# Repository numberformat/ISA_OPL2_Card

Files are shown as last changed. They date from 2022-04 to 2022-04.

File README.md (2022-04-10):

# README

ISA OPL2 Card is a sound card based on Yamaha OPL2 chip, officially known as YM3812. This card is compatible with the AdLib Music Synthesizer Card that was very popular in late 80's - early
90's.

This card is based on a [design from Sergey Kiselev](http://www.malinov.com/Home/sergeys-projects/isa-opl2-card) with the modifications listed in the Revisions Section below.

## Revisions

NOAMi r1
- Added additional footprint for a more commonly available RK097N potentiometer
- Made connector pads shorter since half of them were not making contact with the connector pins.

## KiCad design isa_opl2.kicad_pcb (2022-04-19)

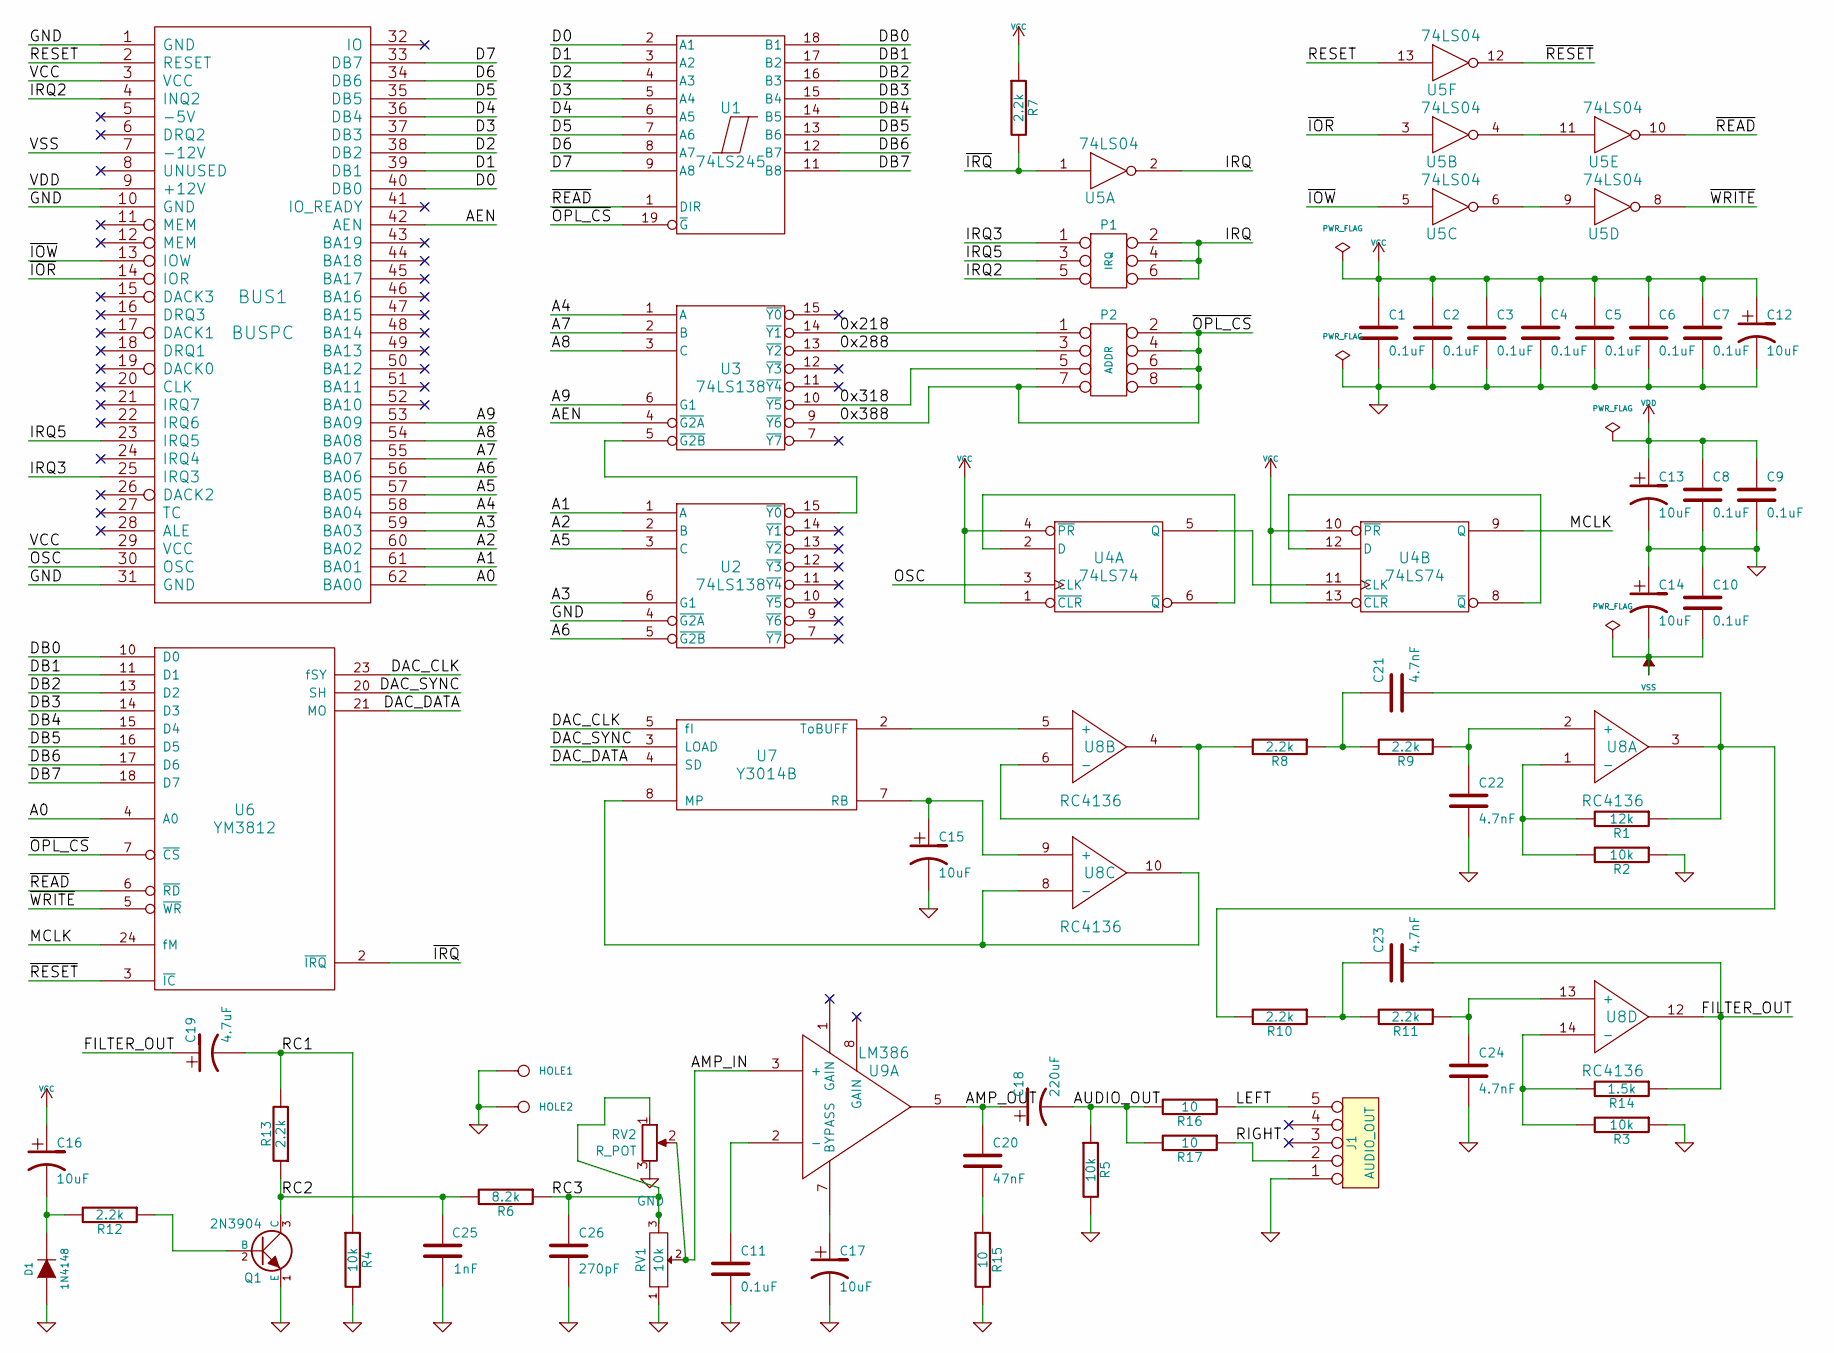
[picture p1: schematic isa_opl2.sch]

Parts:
BUS1: BUSPC
C1, C2, C3, C4, C5, C6, C7, C8, C9, C10, C11: 0.1uF
C12, C13, C14, C15, C16, C17: 10uF
C18: 220uF
C19: 4.7uF
C20: 47nF
C21, C22, C23, C24: 4.7nF
C25: 1nF
C26: 270pF
D1: 1N4148
HOLE1, HOLE2: CONN_1
J1: AUDIO_OUT
P1: IRQ
P2: ADDR
Q1: 2N3904
R1: 12k
R2, R3, R4, R5: 10k
R6: 8.2k
R7, R8, R9, R10, R11, R12, R13: 2.2k
R14: 1.5k
R15, R16, R17: 10
RV1: 10k
RV2: R_POT; Potentiometer_Vishay_T73XW_Horizontal
U1: 74LS245
U2, U3: 74LS138
U4: 74LS74
U5: 74LS04
U6: YM3812
U7: Y3014B
U8: RC4136
U9: LM386

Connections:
/0x218: P2.1, U3.14 (~Y1)
/0x288: P2.3, U3.13 (~Y2)
/0x318: P2.5, U3.10 (~Y5)
/0x388: P2.2, P2.4, P2.6, P2.7, P2.8, U1.19 (~G), U3.9 (~Y6), U6.7 (~CS)
/A0: BUS1.62 (BA00), U6.4 (A0)
/A1: BUS1.61 (BA01), U2.1 (A)
/A2: BUS1.60 (BA02), U2.2 (B)
/A3: BUS1.59 (BA03), U2.6 (G1)
/A4: BUS1.58 (BA04), U3.1 (A)
/A5: BUS1.57 (BA05), U2.3 (C)
/A6: BUS1.56 (BA06), U2.5 (~G2B)
/A7: BUS1.55 (BA07), U3.2 (B)
/A8: BUS1.54 (BA08), U3.3 (C)
/A9: BUS1.53 (BA09), U3.6 (G1)
/AEN: BUS1.42 (AEN), U3.4 (~G2A)
/AMP_IN: RV1.2, RV2.2, U9.3 (+)
/AMP_OUT: C18.1, C20.1, U9.5
/AUDIO_OUT: C18.2, R5.1, R16.2, R17.2
/D0: BUS1.40 (DB0), U1.2 (A1)
/D1: BUS1.39 (DB1), U1.3 (A2)
/D2: BUS1.38 (DB2), U1.4 (A3)
/D3: BUS1.37 (DB3), U1.5 (A4)
/D4: BUS1.36 (DB4), U1.6 (A5)
/D5: BUS1.35 (DB5), U1.7 (A6)
/D6: BUS1.34 (DB6), U1.8 (A7)
/D7: BUS1.33 (DB7), U1.9 (A8)
/DAC_CLK: U6.23 (fSY), U7.5 (fI)
/DAC_DATA: U6.21 (MO), U7.4 (SD)
/DAC_SYNC: U6.20 (SH), U7.3 (LOAD)
/DB0: U1.18 (B1), U6.10 (D0)
/DB1: U1.17 (B2), U6.11 (D1)
/DB2: U1.16 (B3), U6.13 (D2)
/DB3: U1.15 (B4), U6.14 (D3)
/DB4: U1.14 (B5), U6.15 (D4)
/DB5: U1.13 (B6), U6.16 (D5)
/DB6: U1.12 (B7), U6.17 (D6)
/DB7: U1.11 (B8), U6.18 (D7)
/FILTER_OUT: C19.1, C23.2, R14.1, U8.12
/IRQ: P1.2, P1.4, P1.6, U5.2
/IRQ2: BUS1.4 (INQ2), P1.5
/IRQ3: BUS1.25 (IRQ3), P1.1
/IRQ5: BUS1.23 (IRQ5), P1.3
/LEFT: J1.5, R16.1
/MCLK: U4.9 (Q), U6.24 (fM)
/OSC: BUS1.30 (OSC), U4.3 (CLK)
/RC1: C19.2, R4.1, R13.2
/RC2: C25.2, Q1.3 (C), R6.2, R13.1
/RC3: C26.1, R6.1, RV1.3, RV2.1
/RESET: BUS1.2 (RESET), U5.13
/RIGHT: J1.2, R17.1
/~IOR: BUS1.14 (IOR), U5.3
/~IOW: BUS1.13 (IOW), U5.5
/~IRQ: R7.2, U5.1, U6.2 (~IRQ)
/~READ: U1.1 (DIR), U5.10, U6.6 (~RD)
/~RESET: U5.12, U6.3 (~IC)
/~WRITE: U5.8, U6.5 (~WR)
GND: BUS1.1 (GND), BUS1.10 (GND), BUS1.31 (GND), C1.2, C2.2, C3.2, C4.2, C5.2, C6.2, C7.2, C8.2, C9.2, C10.1, C11.2, C12.2, C13.2, C14.1, C15.2, C17.2, C22.2, C24.2, C25.1, C26.2, D1.1 (A), HOLE1.1, HOLE2.1, J1.1, Q1.1 (E), R2.1, R3.1, R4.2, R5.2, R15.2, RV1.1, RV2.3, U1.10 (GND), U2.4 (~G2A), U2.8 (GND), U3.8 (GND), U4.7 (GND), U5.7 (GND), U6.12 (GND), U7.6 (GND), U9.4 (GND)
unnamed: C11.1, U9.2 (-)
unnamed: C15.1, U7.7 (RB), U8.9 (+)
unnamed: C16.2, D1.2 (K), R12.2
unnamed: C17.1, U9.7 (BYPASS)
unnamed: C20.2, R15.1
unnamed: C21.1, R8.1, R9.2
unnamed: C21.2, R1.1, R10.2, U8.3
unnamed: C22.1, R9.1, U8.2 (+)
unnamed: C23.1, R10.1, R11.2
unnamed: C24.1, R11.1, U8.13 (+)
unnamed: Q1.2 (B), R12.1
unnamed: R1.2, R2.2, U8.1 (-)
unnamed: R8.2, U8.4, U8.6 (-)
unnamed: R3.2, R14.2, U8.14 (-)
unnamed: U2.15 (~Y0), U3.5 (~G2B)
unnamed: U4.2 (D), U4.6 (~Q)
unnamed: U4.5 (Q), U4.11 (CLK)
unnamed: U4.8 (~Q), U4.12 (D)
unnamed: U5.6, U5.9
unnamed: U5.4, U5.11
unnamed: U7.2 (ToBUFF), U8.5 (+)
unnamed: U7.8 (MP), U8.8 (-), U8.10
VCC: BUS1.3 (VCC), BUS1.29 (VCC), C1.1, C2.1, C3.1, C4.1, C5.1, C6.1, C7.1, C12.1, C16.1, R7.1, U1.20 (VCC), U2.16 (VCC), U3.16 (VCC), U4.1 (~CLR), U4.4 (~PR), U4.10 (~PR), U4.13 (~CLR), U4.14 (VCC), U5.14 (VCC), U6.1 (VCC), U7.1 (VCC)
VDD: BUS1.9 (+12V), C8.1, C9.1, C13.1, U8.11 (VDD), U9.6 (VDD)
VSS: BUS1.7 (-12V), C10.2, C14.2, U8.7 (VSS)

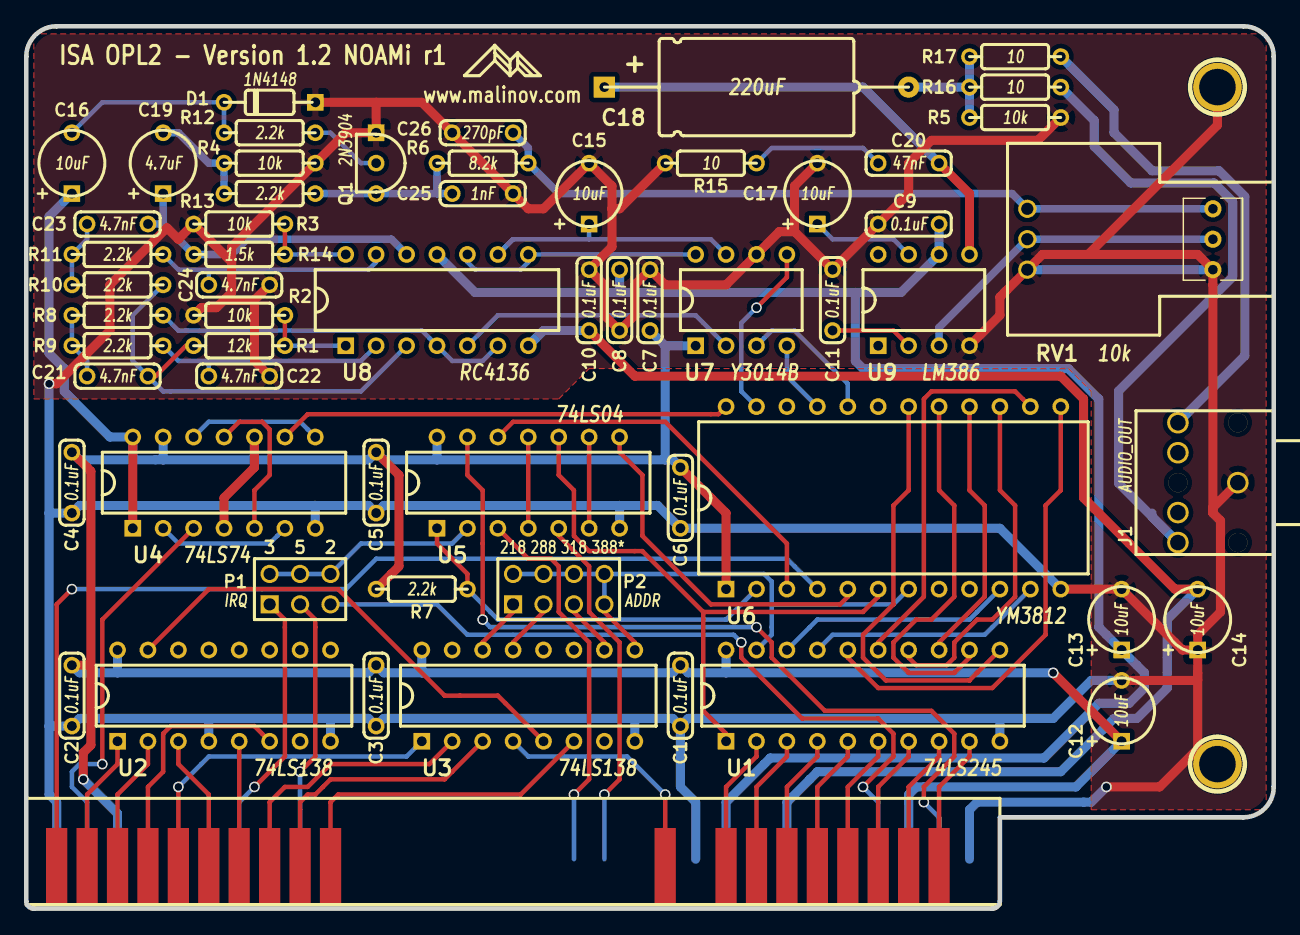
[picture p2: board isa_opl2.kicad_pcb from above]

Board: 2 copper layers, 104.1 x 73.7 mm, 61 parts (0 on the bottom side), 82 nets.

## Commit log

2021-11-06 NOAMi r1 - added additional footprint for cheaper pot and more clearence for 45 deg chamfer
    [isa_opl2.kicad_pcb, isa_opl2.sch]
2021-11-24 Made connector pads shorter since half of them were not making contact with the connector pins
    [isa_opl2.kicad_pcb]
2022-04-19 Added service/support info
    [isa_opl2.kicad_pcb]
